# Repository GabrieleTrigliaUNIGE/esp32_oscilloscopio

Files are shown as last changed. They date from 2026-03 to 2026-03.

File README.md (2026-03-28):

# ⚡ ESP32 Smart Oscilloscope & Function Generator (Dual-Core & Wi-Fi)

Un potente strumento di misura IoT e multifunzione basato su ESP32. Sfrutta il sistema operativo in tempo reale (FreeRTOS) per gestire l'acquisizione dei dati o la generazione di forme d'onda su un core dedicato, garantendo un'interfaccia fluida sia sul display OLED locale sia sul browser web tramite WebSockets.

## ✨ Caratteristiche Principali

* **Strumento 2-in-1:** Oscilloscopio digitale ad alte prestazioni e Generatore di Funzioni integrato (Onde Sinusoidali, Quadre e Triangolari via DAC).
* **Architettura Multi-Core (FreeRTOS):** Elaborazione hardware sul Core 1 (nessun lag) e gestione interfaccia/Wi-Fi sul Core 0.
* **Interfaccia Web Bidirezionale & "State-Aware":** Visualizza l'onda in tempo reale, controlla lo strumento dal browser e ricevi feedback visivi (overlay) se il dispositivo è in modalità Menù o Generatore.
* **Controllo Hardware Smart:** Interfaccia utente a stati multipli navigabile tramite un **Encoder Rotativo Digitale (KY-040)** gestito a interrupt, con riconoscimento intelligente di Click Rapidi e Pressioni Lunghe (Long Press) per tornare al menù principale.
* **Display OLED Locale:** Supporto integrato per display I2C da 1.3" (Chip SH110X) con animazioni avanzate (Circular Progress Bar).
* **Digital Signal Processing (DSP):** Motore matematico avanzato con **Schmitt Trigger software** e isteresi (10%) per un calcolo solido della frequenza e della VMax.
* **Smart Trigger & Roll Mode:** Transizione automatica tra un'onda "congelata" (per segnali veloci) e uno scorrimento continuo (per segnali lenti).
* **Architettura OOP Modulare:** Driver hardware astratti e Macchina a Stati globale facilmente espandibile.

---

## 🧱 Architettura Modulare (Il file `config.h`)

Il firmware è altamente personalizzabile. Puoi accendere o spegnere interi blocchi del sistema utilizzando le direttive del preprocessore:
* `USE_DISPLAY`: Disattivalo per trasformare l'ESP32 in un data-logger "cieco".
* `USE_WIFI` / `USE_WEB_SERVER`: Gestisce la connettività e l'interfaccia remota.
* `USE_CONTROLS`: Abilita/disabilita i controlli fisici. Al suo interno puoi attivare `USE_ENCODER` e `USE_BUTTON`.
* `USE_SIMULATOR`: Sgancia l'hardware e genera un'onda matematica per testare la UI senza cavi fisici!

---

## 🛠️ Componenti Hardware Necessari

* 1x Scheda di sviluppo **ESP32** (es. DevKit V1)
* 1x Display **OLED I2C 1.3"** (Chip SH1106, indirizzo `0x3C`)
* 1x **Encoder Rotativo** (Modulo breakout tipo AZ-Delivery KY-040 con resistenze di pull-up integrate)
* 1x Pulsante fisico (Push-button) per la pausa
* 2x Resistenze dello stesso valore (es. 10kΩ) per il partitore di tensione in ingresso
* Breadboard e cavi jumper

---

### 📐 Schema Elettrico

Ecco lo schema dei collegamenti da realizzare. Per maggiori dettagli, puoi scaricare il [progetto KiCad e il PDF ufficiale nella cartella hardware/](hardware/).

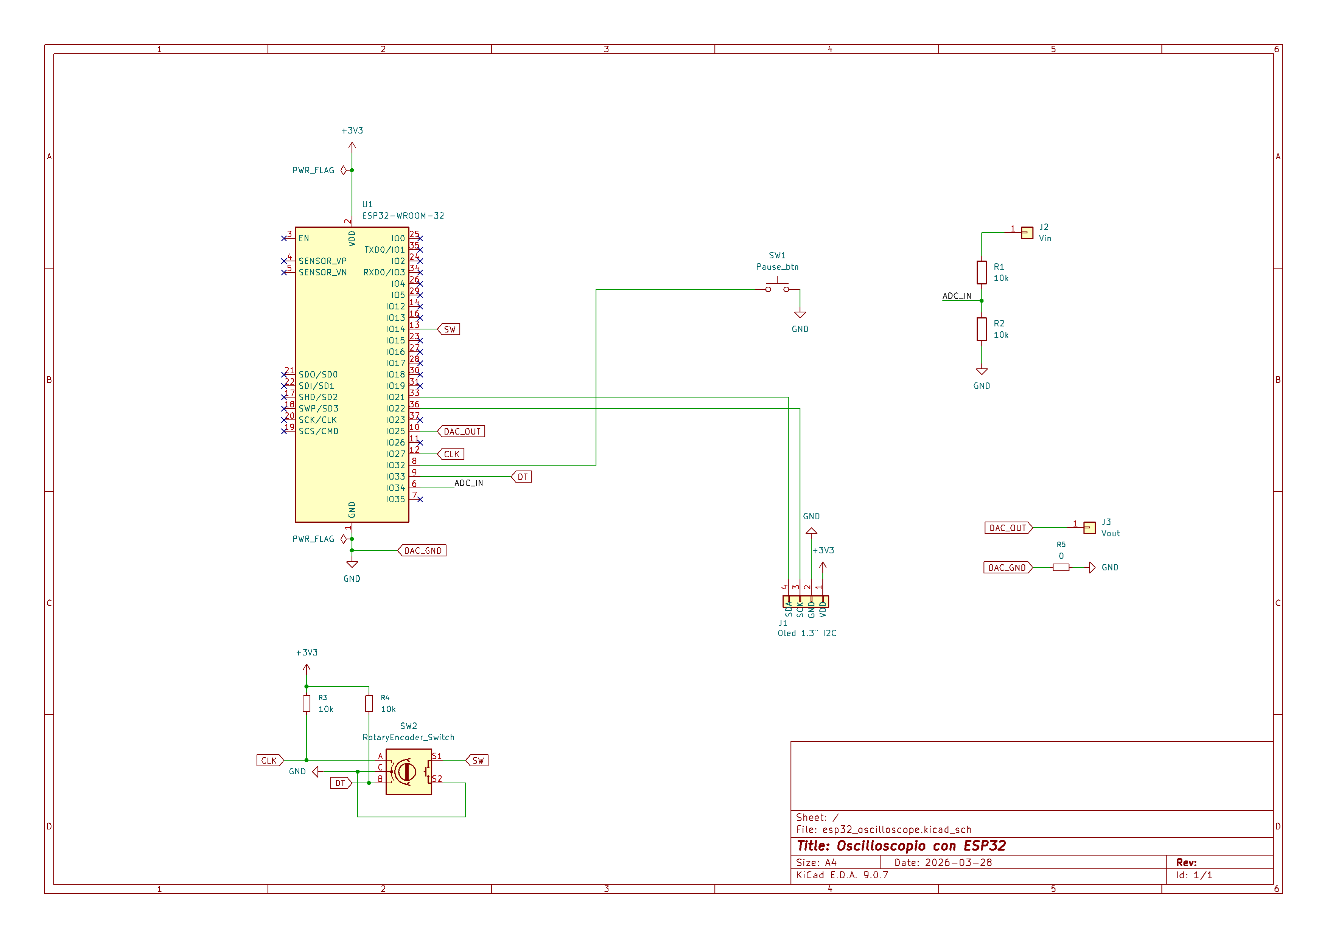
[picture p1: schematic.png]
Schema Elettrico dell'Oscilloscopio ESP32


---

## 🔌 Schema dei Collegamenti (Aggiornato v1.2.0)

| Componente | Pin ESP32 | Note Importanti |
| :--- | :--- | :--- |
| **Segnale In (ADC)** | `GPIO 34` | **MAX 3.3V!** Il partitore dimezza il segnale d'ingresso. |
| **Generatore Out (DAC)**| `GPIO 25` | Uscita analogica reale per la generazione delle onde. |
| **Encoder CLK** | `GPIO 27` | Genera gli impulsi di rotazione. |
| **Encoder DT** | `GPIO 33` | Determina la direzione della rotazione. |
| **Encoder SW** | `GPIO 14` | Pulsante integrato (Click per selezione, Long Press per Indietro). |
| **Encoder + (VCC)**| `3.3V` | **Non alimentare a 5V**, altrimenti brucerai i pin dell'ESP32! |
| **Pulsante HOLD**| `GPIO 32` | Collegare l'altro piedino al `GND` (Pull-Up interno usato). |
| **OLED SDA** | `GPIO 21` | Linea dati I2C. |
| **OLED SCL** | `GPIO 22` | Linea di clock I2C. |
| **GND in Comune**| `GND` | **Cruciale:** Unire il GND del circuito in esame al GND dell'ESP32. |

> ⚠️ **AVVERTENZA DI SICUREZZA:** L'ADC dell'ESP32 tollera un massimo assoluto di 3.3V. Tensioni superiori danneggeranno irreparabilmente la scheda.

---

## 💻 Installazione e Software

Questo progetto è stato sviluppato utilizzando **PlatformIO**. 

1. **Clona questa repository:**
   ```bash
   git clone [https://github.com/TUO_NOME_UTENTE/NOME_REPO.git](https://github.com/TUO_NOME_UTENTE/NOME_REPO.git)

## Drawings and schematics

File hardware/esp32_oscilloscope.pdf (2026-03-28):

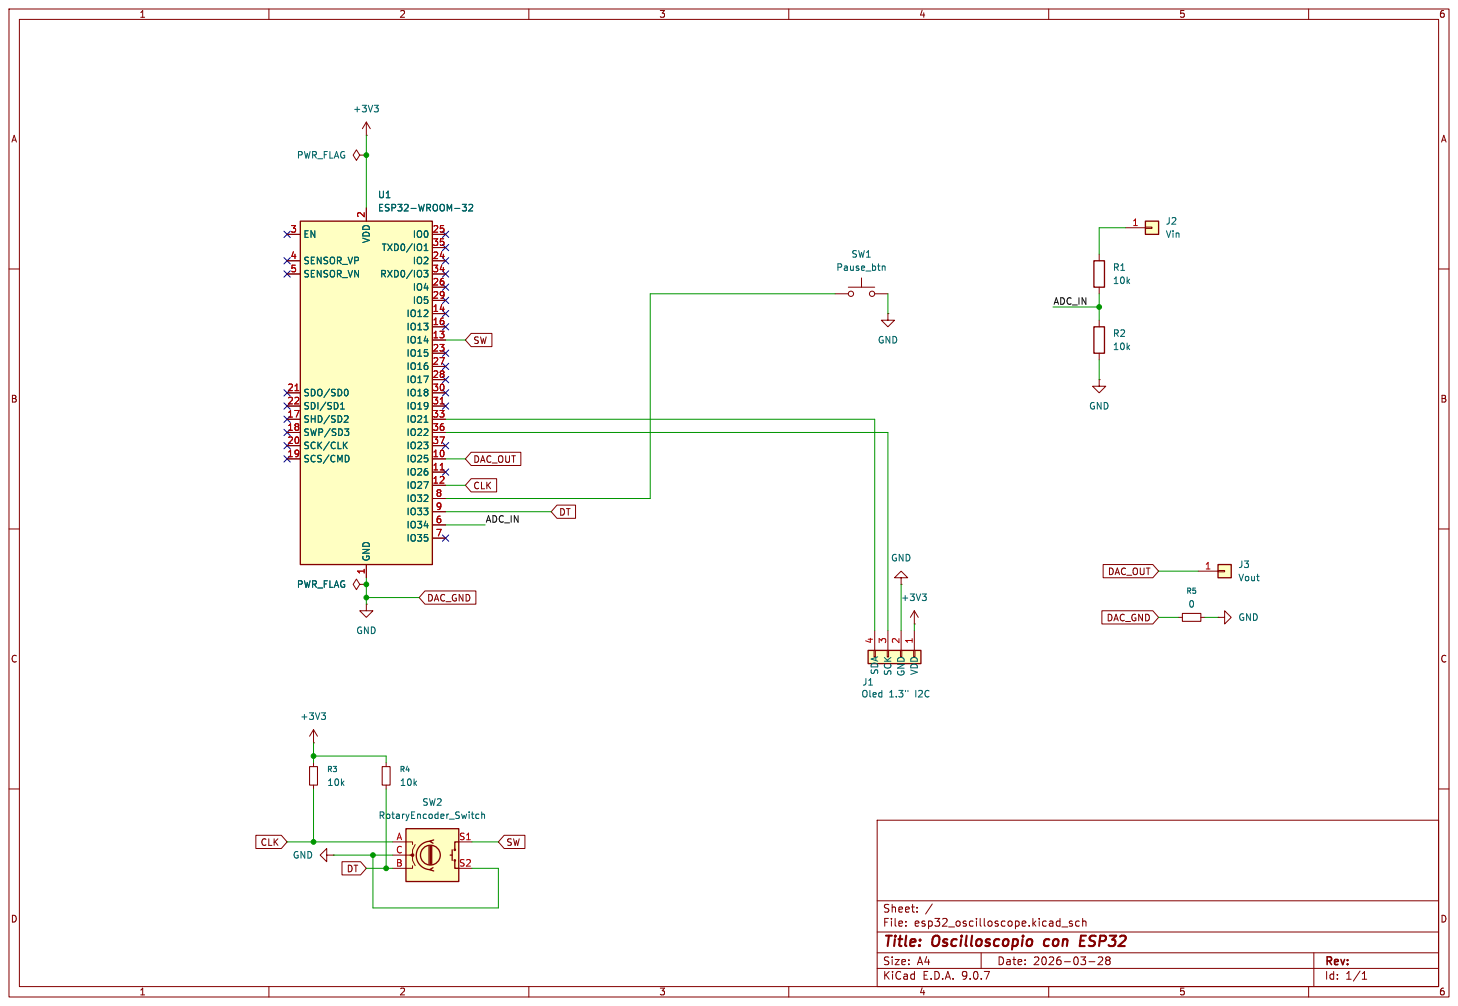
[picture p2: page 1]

File: esp32_oscilloscope.kicad_sch Sheet: /
Id: 1/1 Title: Oscilloscopio con ESP32

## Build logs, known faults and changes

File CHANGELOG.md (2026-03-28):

# Changelog

Tutte le modifiche importanti a questo progetto verranno documentate in questo file.
Il formato è basato su [Keep a Changelog](https://keepachangelog.com/it-IT/1.0.0/), e questo progetto aderisce al [Semantic Versioning](https://semver.org/lang/it/).

## [1.2.0] - 2026-03-28
### Aggiunto
- **Generatore di Funzioni Integrato**: Nuova modalità per generare onde sinusoidali, quadre e triangolari tramite il DAC interno (Pin 25). Frequenza regolabile al volo (1-500 Hz).
- **Menù Principale Navigabile**: Introdotta una schermata OLED dedicata per passare agilmente dalla modalità Oscilloscopio alla modalità Generatore.
- **Web Dashboard "State-Aware"**: L'interfaccia web ora riconosce lo stato del dispositivo. Oscura dinamicamente il grafico e mostra eleganti messaggi di stato in sovrimpressione quando si naviga nel menù o si usa il generatore.
- **UI/UX Display**: Aggiunta una *Circular Progress Bar* (animazione radiale) in alto a destra per fornire un feedback visivo istantaneo durante la pressione lunga (Long Press) dell'encoder.

### Modificato
- **Refactoring Dual-Core & Macchina a Stati**: Il codice è stato diviso in moduli isolati (`app_menu`, `app_oscilloscope`, `app_generator`). Il Core 0 gestisce UI e Wi-Fi, il Core 1 l'acquisizione/generazione hardware.
- **Aggiornamento SmartEncoder**: Libreria resa totalmente non-bloccante. Mantiene gli interrupt (`IRAM_ATTR`) per la rotazione, ma ora integra un polling intelligente basato su `millis()` per il pulsante, supportando click rapidi e pressioni lunghe.
- **Nuovo Pinout Hardware**: Layout dei pin riorganizzato per fare spazio al Generatore d'Onda (Encoder spostato dai pin 25/26 ai pin 27/33, aggiunto SW sul pin 14).

### Risolto
- **Bug visivo CSS Web Dashboard**: Risolto il problema dell'overlay scuro che sbordava dal canvas applicando un *Wrapper Container* con `overflow: hidden`.

---

## [1.1.0] - 2026-03-16
### Aggiunto
- **Web UI Bidirezionale**: Aggiunti pulsanti all'interfaccia web per controllare il timebase e mettere in pausa l'oscilloscopio da remoto tramite WebSockets.
- **Inserimento Manuale Timebase**: Possibilità di digitare il valore esatto del timebase direttamente dalla pagina web.
- **Controllo Hold-to-Repeat**: Pressione continua dei pulsanti web (supporto touch e mouse tramite Pointer Events) per scorrere rapidamente i valori.
- **Supporto Encoder KY-040**: Sostituito il vecchio potenziometro analogico con un encoder rotativo digitale per una precisione assoluta.
- **Architettura OOP**: Introdotti i moduli `SmartEncoder` e `SmartButton` per un'astrazione pulita dell'hardware.

### Modificato
- Refactoring del motore di acquisizione: Rimossa la gestione dei rimbalzi e degli stati dal `main.cpp`, ora delegata interamente agli oggetti hardware.
- Sostituita la lettura analogica dei controlli con una Macchina a Stati (State Machine) gestita via Interrupt per l'encoder, eliminando lag e falsi contatti.

### Risolto
- Bug fix sull'interfaccia web: Risolto conflitto sull'ID HTML che impediva il corretto aggiornamento del campo input del timebase.

---

## [1.0.0] - 2026-03-11
### Aggiunto
- Release iniziale.
- Architettura Dual-Core basata su FreeRTOS.
- Supporto per display OLED I2C (SH110X).
- Interfaccia Web di sola lettura tramite WebSockets e LittleFS.
- Lettura hardware tramite potenziometro analogico (GPIO 35) e pulsante fisico (GPIO 32).
- Motore DSP con Schmitt Trigger e Roll Mode.

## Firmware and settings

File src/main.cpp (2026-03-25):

#include "config.h"

// Inizializzazione delle variabili globali condivise
volatile AppState statoAttuale = STATE_MENU;
volatile bool nuovoFramePronto = false;
volatile int timebaseCondiviso = DEFAULT_TIMEBASE;
volatile bool holdAttivo = false;

float bufferAcquisizione[BUFFER_SIZE];
float bufferDisplay[BUFFER_SIZE];      

/// =========================================================
// 📺 TASK CORE 0: Orchestratore Grafico e Web
// =========================================================
void TaskCore0_SchermoWeb(void * pvParameters) {
  for(;;) { 
    #ifdef USE_WIFI
    if (isWiFiConnesso()) { 
      gestisciWeb(); 
      
      // NUOVO: Inviamo lo stato corrente al Browser
      #ifdef USE_WEB_SERVER
      if (statoAttuale == STATE_MENU) {
        extern volatile int voceMenuSelezionata;
        inviaDatiMenuWeb(voceMenuSelezionata);
      } else if (statoAttuale == STATE_GENERATOR) {
        extern volatile int freqGeneratore;
        extern volatile int tipoOnda;
        inviaDatiGeneratoreWeb(freqGeneratore, tipoOnda);
      }
      #endif
    }
    #endif

    // 1. Leggiamo subito se stiamo premendo il tasto
    int progresso = 0;
    #ifdef USE_CONTROLS
    progresso = getProgressoPressione();
    #endif

    // 2. AGGIORNAMENTO GRAFICA (Solo se NON stiamo premendo a lungo!)
    if (progresso == 0) {
      switch (statoAttuale) {
        case STATE_MENU:
          taskGraficaMenu();
          break;
        case STATE_OSCILLOSCOPE:
          taskGraficaOscilloscopio();
          break;
        case STATE_GENERATOR:
          taskGraficaGeneratore();
          break;
      }
    }
    
    // =========================================================
    // 🪄 MAGIA OVERLAY: Animazione Long Press Globale
    // =========================================================
    #if defined(USE_DISPLAY) && defined(USE_CONTROLS)
    static int ultimoProgresso = 0;
    
    // Se il dito è premuto, disegniamo solo la barra sopra l'ultimo frame
    if (progresso > 0 && abs(progresso - ultimoProgresso) > 2) {
      disegnaBarraPressione(progresso);
      display.display(); 
      ultimoProgresso = progresso;
    } 
    // Appena rilasciamo, forziamo il ridisegno completo per far sparire la barra
    else if (progresso == 0 && ultimoProgresso > 0) {
      ultimoProgresso = 0;
      if (statoAttuale == STATE_OSCILLOSCOPE) nuovoFramePronto = true;
      else if (statoAttuale == STATE_MENU) aggiornaSchermoMenu = true;
      else if (statoAttuale == STATE_GENERATOR) aggiornaSchermoGen = true;
    }
    #endif
    // =========================================================

    vTaskDelay(10 / portTICK_PERIOD_MS); 
  }
}

// =========================================================
// ⚡ TASK CORE 1: Orchestratore Input e Logica
// =========================================================
void TaskCore1_Acquisizione(void * pvParameters) {
  unsigned long ultimoCampionamento = 0;
  
  for(;;) {
    #ifdef USE_CONTROLS
    ButtonEvent eventoTasto = leggiEventoEncoder(); 
    int valoreEncoder = leggiTimebase();            
    #else
    ButtonEvent eventoTasto = BTN_NONE;
    int valoreEncoder = DEFAULT_TIMEBASE;
    #endif

    // Smistamento alla logica corretta
    switch (statoAttuale) {
      case STATE_MENU:
        taskLogicaMenu(eventoTasto, valoreEncoder);
        break;
      case STATE_OSCILLOSCOPE:
        taskLogicaOscilloscopio(eventoTasto, valoreEncoder, ultimoCampionamento);
        break;
      case STATE_GENERATOR:
        taskLogicaGeneratore(eventoTasto, valoreEncoder);
        break;
    }
  }
}

// =========================================================
// 🚀 SETUP (Invariato)
// =========================================================
void setup() {
  Serial.begin(115200);
  analogReadResolution(12);
  
  #ifdef USE_CONTROLS
  inizializzaControlli();
  #endif

  #ifdef USE_DISPLAY
  inizializzaDisplay(); 
  Wire.setClock(400000); 
  #endif

  #ifdef USE_WIFI
  if (inizializzaWiFi()) {
    inizializzaWebServer(); 
    #ifdef USE_DISPLAY
      mostraInfoBoot("1.2.0-MODULAR", WiFi.SSID(), WiFi.localIP().toString());
      delay(3000); 
    #endif
  }
  #endif

  xTaskCreatePinnedToCore(TaskCore0_SchermoWeb, "TaskSchermo", 10000, NULL, 1, NULL, 0);
  xTaskCreatePinnedToCore(TaskCore1_Acquisizione, "TaskAcq", 10000, NULL, 2, NULL, 1);
}

void loop() { vTaskDelete(NULL); }

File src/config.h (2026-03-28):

#ifndef CONFIG_H
#define CONFIG_H

#include <Arduino.h>
#include <math.h>

// --- MACCHINA A STATI GLOBALE ---
enum AppState {
  STATE_MENU,           // 0: Siamo nel menù principale
  STATE_OSCILLOSCOPE,   // 1: Siamo nell'oscilloscopio
  STATE_GENERATOR       // 2: Siamo nel generatore d'onda
};

enum ButtonEvent {
  BTN_NONE,       // Nessuna azione
  BTN_CLICK,      // Click veloce (Invio)
  BTN_LONG_PRESS  // Pressione prolungata (Indietro)
};

// ==========================================
// 🎚️ INTERRUTTORI DI COMPILAZIONE (FEATURES)
// ==========================================
#define USE_DISPLAY      // Attiva/Disattiva lo schermo OLED
#define USE_WIFI         // Attiva/Disattiva Wi-Fi e Web Server
#define USE_PROCESSING   // Attiva/Disattiva i calcoli matematici (VMax, Freq)
#define USE_WEB_SERVER   // Attiva/Disattiva il Web Server (richiede USE_WIFI)

#define USE_CONTROLS     // Attiva/Disattiva in blocco i controlli fisici
#ifdef USE_CONTROLS
  #define USE_ENCODER    // Attiva la logica dell'Encoder Rotativo KY-040
  #define USE_BUTTON     // Attiva la logica del Pulsante fisico
#endif

// ==========================================
// 🧲 MOTORE DI ACQUISIZIONE (Scegline UNO SOLO)
// ==========================================
#define USE_REAL_ADC       // Legge il segnale vero dal Pin 34
// #define USE_SIMULATOR      // Genera una finta onda sinusoidale per i test software

// ==========================================
// 📌 PIN E IMPOSTAZIONI GLOBALI
// ==========================================
#define PIN_SEGNALE 34
#define V_REF 3.3
#define PARTITORE_MOLTIPLICATORE 2.0 
#define BUFFER_SIZE 128

// Limiti e default della scala dei tempi
#define MIN_TIMEBASE 20
#define MAX_TIMEBASE 100000
#define DEFAULT_TIMEBASE 9000

#ifdef USE_CONTROLS
  #ifdef USE_ENCODER
    #define ENCODER_PIN_CLK 27  // Spostato dal 25 per liberare il DAC
    #define ENCODER_PIN_DT  33  // Spostato dal 26
    #define ENCODER_PIN_SW  14
    #define ENCODER_STEP    50  // Quanto varia il timebase a ogni scatto
    #define ENCODER_LONG_PRESS_MS 400
  #endif

  #ifdef USE_BUTTON
    #define PIN_PULSANTE 32     // Pin del pulsante fisico per la pausa/selezione
  #endif
#endif

// Pin del DAC per il GdF
#define PIN_GENERATORE 25

// ==========================================
// 🧩 CLASSI DEI DISPOSITIVI (HARDWARE ABSTRACTION)
// ==========================================
#ifdef USE_ENCODER
class SmartEncoder {
  private:
    static volatile int value;
    static volatile uint8_t statoPrecedente;
    static volatile int contatoreInterno;
    static int step, minVal, maxVal, pinCLK, pinDT, pinSW;
    
    // Variabili per la gestione del tasto integrato
    static unsigned long tempoInizioPressione;
    static bool statoPrecedenteSW;
    static bool inPressione;
    static bool lungaPressioneSegnalata;

    static void IRAM_ATTR isr();
  public:
    static void begin(int clk, int dt, int sw, int startValue, int stepVal, int minimum, int maximum);
    static int getValue();
    static void addValue(int delta);
    static void setValue(int val);
    static ButtonEvent getButtonEvent(); 
    static int getLongPressProgress();
};
#endif

#ifdef USE_BUTTON
class SmartButton {
  private:
    int pin;
    unsigned long ultimoTempoPressione;
  public:
    SmartButton();
    void begin(int pinButton);
    bool hasBeenClicked(); 
};
#endif

// ==========================================
// 📺 MODULO DISPLAY
// ==========================================
#ifdef USE_DISPLAY
  #include <Wire.h>
  #include <Adafruit_GFX.h>
  #include <Adafruit_SH110X.h>
  
  #define SCREEN_WIDTH 128
  #define SCREEN_HEIGHT 64
  #define OLED_RESET -1
  
  void inizializzaDisplay();
  void disegnaOnda(float* buffer, int timebase, bool inHold, float vMax, float freq);
  void disegnaBarraPressione(int progresso);
  void mostraInfoBoot(String versione, String rete, String ip);
#endif

// ==========================================
// 🌐 MODULO WI-FI E WEB
// ==========================================
#ifdef USE_WIFI
  #include "arduino_secrets.h" 
  
  bool inizializzaWiFi();
  bool isWiFiConnesso();
  
  #ifdef USE_WEB_SERVER
    #include <WebServer.h>
    #include <WebSocketsServer.h>
    #include <LittleFS.h>

    void inizializzaWebServer();
    void gestisciWeb();
    void inviaDatiWeb(float* buffer, int timebase, float vMax, float freq, bool inHold);
    void inviaDatiMenuWeb(int voceSelezionata);
    void inviaDatiGeneratoreWeb(int freq, int tipo);
  #endif
#endif

// ==========================================
// 🎛️ MODULO CONTROLLI GLOBALI
// ==========================================
#ifdef USE_CONTROLS
  void inizializzaControlli();
  int leggiTimebase();
  ButtonEvent leggiEventoEncoder();
  bool gestisciPulsanteHold(bool statoAttuale, volatile bool &nuovoFramePronto);
  int getProgressoPressione();
#endif
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

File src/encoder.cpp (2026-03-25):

#include "config.h"

#ifdef USE_ENCODER

// Inizializzazione della memoria per le variabili statiche
volatile int SmartEncoder::value = DEFAULT_TIMEBASE;
volatile uint8_t SmartEncoder::statoPrecedente = 0;
volatile int SmartEncoder::contatoreInterno = 0;
int SmartEncoder::step = ENCODER_STEP;
int SmartEncoder::minVal = MIN_TIMEBASE;
int SmartEncoder::maxVal = MAX_TIMEBASE;
int SmartEncoder::pinCLK = -1;
int SmartEncoder::pinDT = -1;
int SmartEncoder::pinSW = -1;

// Inizializzazione variabili per il tasto
unsigned long SmartEncoder::tempoInizioPressione = 0;
bool SmartEncoder::statoPrecedenteSW = HIGH;
bool SmartEncoder::inPressione = false;
bool SmartEncoder::lungaPressioneSegnalata = false;

void IRAM_ATTR SmartEncoder::isr() {
  uint8_t CLK_stato = digitalRead(pinCLK);
  uint8_t DT_stato = digitalRead(pinDT);
  
  uint8_t statoCorrente = (CLK_stato << 1) | DT_stato;
  uint8_t movimento = (statoPrecedente << 2) | statoCorrente;
  statoPrecedente = statoCorrente;

  if(movimento == 0b1101 || movimento == 0b0100 || movimento == 0b0010 || movimento == 0b1011) {
    contatoreInterno++; 
  } else if(movimento == 0b1110 || movimento == 0b0111 || movimento == 0b0001 || movimento == 0b1000) {
    contatoreInterno--; 
  }
  
  if (contatoreInterno >= 2) {
    value += step;
    contatoreInterno = 0;
  } else if (contatoreInterno <= -2) {
    value -= step;
    contatoreInterno = 0;
  }
  
  if (value < minVal) value = minVal;
  if (value > maxVal) value = maxVal;
}

void SmartEncoder::begin(int clk, int dt, int sw, int startValue, int stepVal, int minimum, int maximum) {
  pinCLK = clk; pinDT = dt; pinSW = sw; 
  value = startValue; step = stepVal; minVal = minimum; maxVal = maximum;
  
  pinMode(pinCLK, INPUT_PULLUP);
  pinMode(pinDT, INPUT_PULLUP);
  pinMode(pinSW, INPUT_PULLUP); // Setup del pin del tasto
  
  attachInterrupt(digitalPinToInterrupt(pinCLK), isr, CHANGE);
  attachInterrupt(digitalPinToInterrupt(pinDT), isr, CHANGE);
}

int SmartEncoder::getValue() { return value; }
void SmartEncoder::addValue(int delta) { setValue(value + delta); }

void SmartEncoder::setValue(int val) {
  value = val;
  if (value < minVal) value = minVal;
  if (value > maxVal) value = maxVal;
}

// Nuova logica Non-Bloccante per il Tasto dell'Encoder
ButtonEvent SmartEncoder::getButtonEvent() {
  bool statoAttuale = digitalRead(pinSW);
  unsigned long tempoAttuale = millis();
  ButtonEvent evento = BTN_NONE;

  // 1. Pressione del tasto (con anti-rimbalzo di 50ms)
  if (statoAttuale == LOW && statoPrecedenteSW == HIGH && (tempoAttuale - tempoInizioPressione > 50)) {
    tempoInizioPressione = tempoAttuale;
    inPressione = true;
    lungaPressioneSegnalata = false;
  }

  // 2. Tasto tenuto premuto (Long Press)
  if (statoAttuale == LOW && inPressione) {
    if (!lungaPressioneSegnalata && (tempoAttuale - tempoInizioPressione > ENCODER_LONG_PRESS_MS)) {
      evento = BTN_LONG_PRESS;
      lungaPressioneSegnalata = true;
    }
  }

  // 3. Rilascio del tasto (Click)
  if (statoAttuale == HIGH && statoPrecedenteSW == LOW) {
    if (inPressione && !lungaPressioneSegnalata) {
      if (tempoAttuale - tempoInizioPressione > 50) { // Anti-rimbalzo al rilascio
        evento = BTN_CLICK;
      }
    }
    inPressione = false;
  }

  statoPrecedenteSW = statoAttuale;
  return evento;
}

// Calcola la percentuale di completamento del Long Press (0-100)
int SmartEncoder::getLongPressProgress() {
  if (!inPressione || lungaPressioneSegnalata) return 0;
  
  unsigned long tempoAttuale = millis();
  if (tempoAttuale - tempoInizioPressione < 50) return 0; // Debounce iniziale
  
  // Mappiamo il tempo trascorso in percentuale
  int progresso = map(tempoAttuale - tempoInizioPressione, 50, ENCODER_LONG_PRESS_MS, 0, 100);
  return constrain(progresso, 0, 100); // Assicuriamoci che non superi il 100%
}

#endif // USE_ENCODER

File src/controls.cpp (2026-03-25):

#include "config.h"

#ifdef USE_CONTROLS

#ifdef USE_BUTTON
  SmartButton btnHold;
#endif

void inizializzaControlli() {
  #ifdef USE_ENCODER
    SmartEncoder::begin(ENCODER_PIN_CLK, ENCODER_PIN_DT, ENCODER_PIN_SW, DEFAULT_TIMEBASE, ENCODER_STEP, MIN_TIMEBASE, MAX_TIMEBASE);
  #endif
  
  #ifdef USE_BUTTON
    btnHold.begin(PIN_PULSANTE);
  #endif
}

int leggiTimebase() {
  #ifdef USE_ENCODER
    return SmartEncoder::getValue(); 
  #else
    return DEFAULT_TIMEBASE;
  #endif
}

ButtonEvent leggiEventoEncoder() {
  #ifdef USE_ENCODER
    return SmartEncoder::getButtonEvent();
  #else
    return BTN_NONE;
  #endif
}

bool gestisciPulsanteHold(bool statoAttuale, volatile bool &nuovoFramePronto) {
  #ifdef USE_BUTTON
    if (btnHold.hasBeenClicked() == BTN_CLICK) {
      statoAttuale = !statoAttuale; 
      nuovoFramePronto = true;      
    }
    return statoAttuale;
  #else
    return statoAttuale;
  #endif
}

int getProgressoPressione() {
  #ifdef USE_ENCODER
    return SmartEncoder::getLongPressProgress();
  #else
    return 0;
  #endif
}

#endif // USE_CONTROLS

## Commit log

2026-03-07 ESP32_Oscilloscopio: Primo Commit
2026-03-07 Add README for ESP32 Smart Oscilloscope project
    Added detailed project description, features, hardware components, connection schema, and installation instructions for the ESP32 Smart Oscilloscope.
2026-03-08 Correzione bug HOLD e miglioramento stabilità lettura da potenziometro
    [main.cpp, web_server.cpp]
2026-03-09 BUG Fix: blocco WiFi + miglioramento modularità
    [config.h, main.cpp, web_server.cpp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]
2026-03-09 Aggiunta modalità di simulazione per testing + collassamento librerie componenti nel file config.h
2026-03-09 Migliorata funzione di calcolo statistiche
2026-03-10 Release v1.0.0 - ESP32 Smart Oscilloscope (Stable)
    [esp32_oscilloscope.kicad_sch]
2026-03-16 Rimpiazzato Potenziometro 10k con Encoder Rotativo KY-040
2026-03-16 refactor: separati file per encoder e switch
2026-03-16 hardware: aggiornato schema elettrico per v1.1.0
    Sostituito potenziometro analogico con encoder rotativo. Aggiunto connettore a 5 pin per modulo KY-040 ed esportato il nuovo schematic.png per il README.
    [esp32_oscilloscope.kicad_sch]
2026-03-25 Cambio Pinout
    per liberare GPIO 25 per futura implementazione di generazione funzioni
2026-03-25 Aggiunta menu!
    Aggiunto menù per la navigazione tra le varie modalità del dispositivo + predisposizione ad aggiungere la funzionalità di GdF
2026-03-25 feat: GdF
    Aggiunto generatore di funzioni funzionante tramite menu
2026-03-28 Release v1.2.0: L'aggiornamento "Multifunzione"
    Questa major release trasforma l'ESP32 da semplice oscilloscopio a vero e proprio strumento di misura multifunzione, introducendo un'architettura modulare.
    Novità principali:
    - Aggiunto Generatore di Funzioni (Onde Sinusoidali, Quadre, Triangolari) via pin DAC.
    - Introdotto Menù Principale su OLED per commutare le modalità di funzionamento.
    - Web Dashboard "State-Aware": l'UI web ora riconosce lo stato dell'hardware e oscura il grafico mostrando overlay informativi.
    - Nuova UI OLED: aggiunta una "Circular Progress Bar" per il feedback visivo del Long Press.
    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
2026-03-28 Fix: Aggiornati schemi KiCad e pinout per la release v1.2.0
    [esp32_oscilloscope.kicad_sch]
